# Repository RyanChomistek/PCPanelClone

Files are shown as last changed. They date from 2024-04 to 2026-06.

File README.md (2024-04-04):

To install go to releases and download and run the installer

once installed it should automatically start. it will auto generate a file called MixerSettings.json in your documents folder
 - in the file there is an array of dials, the index in the array corresponds to the index of the dial
 - for each dial there are three properties, Color, Target, and Processes
   - Color: an array that has 3 ints representing the color of the dial led
   - Target what the dial does. currently there are three states
     - 0: target processes (there should be annother property named Processes on the object). This means that the mixer will set the volume of all of the listed processes
     - 1: Master, sets the master volume
     - 2: Device, sets the volume of a specific output device (not sure if this one works yet)
     - 3: focused, set the volume of the currently focused window
   - Processes: an array of process strings. if Target is set to 3, then it will use this list to find the processes it wants to change

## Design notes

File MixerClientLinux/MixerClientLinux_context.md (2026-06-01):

---
name: project-linux-port
description: "Linux port of Windows MixerClient HID driver into MixerClientLinux — API substitutions, architecture, and build deps"
metadata: 
  node_type: memory
  type: project
  originSessionId: 93b12617-98bc-4457-a38f-4e3386a606ed
---

# MixerClientLinux — Linux port of MixerClient

Created `PCPanelClone/MixerClientLinux/` as a Linux equivalent of `PCPanelClone/MixerClient/`.
Only `.h` and `.cpp` files were ported (`.sln`/`.vcxproj` replaced with `CMakeLists.txt`).

## Files

| File | Notes |
|---|---|
| `HidReader.h/.cpp` | Linux HID layer |
| `VolumeMixerController.h/.cpp` | PulseAudio audio control |
| `MixerClient.cpp` | Entry point |
| `Util.h` | Error macros (int-based, not HRESULT) |
| `Holder.h` | Copied verbatim (generic C++) |
| `scope_guard.h` | Copied verbatim (pure C++) |
| `CMakeLists.txt` | C++20, links hidapi-hidraw + libpulse + x11 + nlohmann_json |

## Key API substitutions

| Windows | Linux |
|---|---|
| `SetupDiGetClassDevs` / `SetupDiEnumDeviceInterfaces` | `hid_enumerate()` (libhidapi) |
| `CreateFile` + `ReadFile`/`WriteFile` with `OVERLAPPED` | `hid_open_path` + `hid_read_timeout` / `hid_write` |
| `HidP_GetValueCaps` / `HidP_GetButtonCaps` / `HidP_GetData` | Custom HID descriptor parser using `HIDIOCGRDESC` ioctl + bit extraction |
| WASAPI (`IMMDevice`, `IAudioSessionManager2`, `ISimpleAudioVolume`) | PulseAudio threaded mainloop (`pa_context_get_sink_input_info_list`, `pa_context_set_sink_input_volume`) |
| `IAudioEndpointVolume` | `pa_context_get/set_sink_volume_by_name` |
| `GetForegroundWindow` + `QueryFullProcessImageNameW` | X11 `XGetInputFocus` + `_NET_WM_PID` + `/proc/<pid>/comm` |
| `SHGetFolderPath(CSIDL_PERSONAL)` | `getenv("HOME")` |
| `std::wstring` process names | `std::string` (UTF-8) |
| `Sleep(1000)` | `sleep(1)` |

## HID device target

Device filter: `usagePage == 0x01` (Generic Desktop), `usage == 0x37` (Dial).
The HID descriptor parser reads via `HIDIOCGRDESC` ioctl on the `/dev/hidraw*` node,
then parses Variable/Array input items, building `hidValues` (dials) and `hidButtons` maps
keyed by sequential DataIndex — matching Windows `HidP_GetData` semantics.

## Audio notes

- PulseAudio wrapper (`PulseSession` class) uses threaded mainloop with lock/wait/signal pattern.
- Per-app volume matches by substring of `PA_PROP_APPLICATION_PROCESS_BINARY`.
- Process names in `MixerSettings.json` need updating from `"firefox.exe"` → `"firefox"` etc.
- Settings file written to `$HOME/MixerSettings.json`.

## Build

```bash
cmake -B build -DCMAKE_BUILD_TYPE=Release
cmake --build build
```

Dependencies: `hidapi-hidraw`, `libpulse`, `x11`, `nlohmann_json`

udev rule needed to access `/dev/hidraw*` without root (Arduino Micro VID/PID, group `users` since `plugdev` doesn't exist on Arch):
```
SUBSYSTEM=="hidraw", ATTRS{idVendor}=="2341", ATTRS{idProduct}=="8037", MODE="0660", GROUP="users"
```
Install: `sudo tee /etc/udev/rules.d/99-arduino-micro.rules`, then `sudo udevadm control --reload && sudo udevadm trigger`

## Running as a background service

Systemd user service at `~/.config/systemd/user/mixer-client.service`:
```ini
[Unit]
Description=PCPanel Mixer Client
After=graphical-session.target pulseaudio.service

[Service]
ExecStart=/home/ryanc/github/PCPanelClone/MixerClientLinux/MixerClientLinux
Restart=on-failure
RestartSec=3

[Install]
WantedBy=default.target
```

```bash
systemctl --user daemon-reload
systemctl --user enable --now mixer-client.service
journalctl --user -u mixer-client.service -f   # view logs
```

## IDE diagnostics note

`std::ranges::sort` on lines 261–262 of `HidReader.cpp` shows a false-positive error in the IDE
because the parser doesn't see C++20 from CMake. Compiles correctly with `-std=c++20`.

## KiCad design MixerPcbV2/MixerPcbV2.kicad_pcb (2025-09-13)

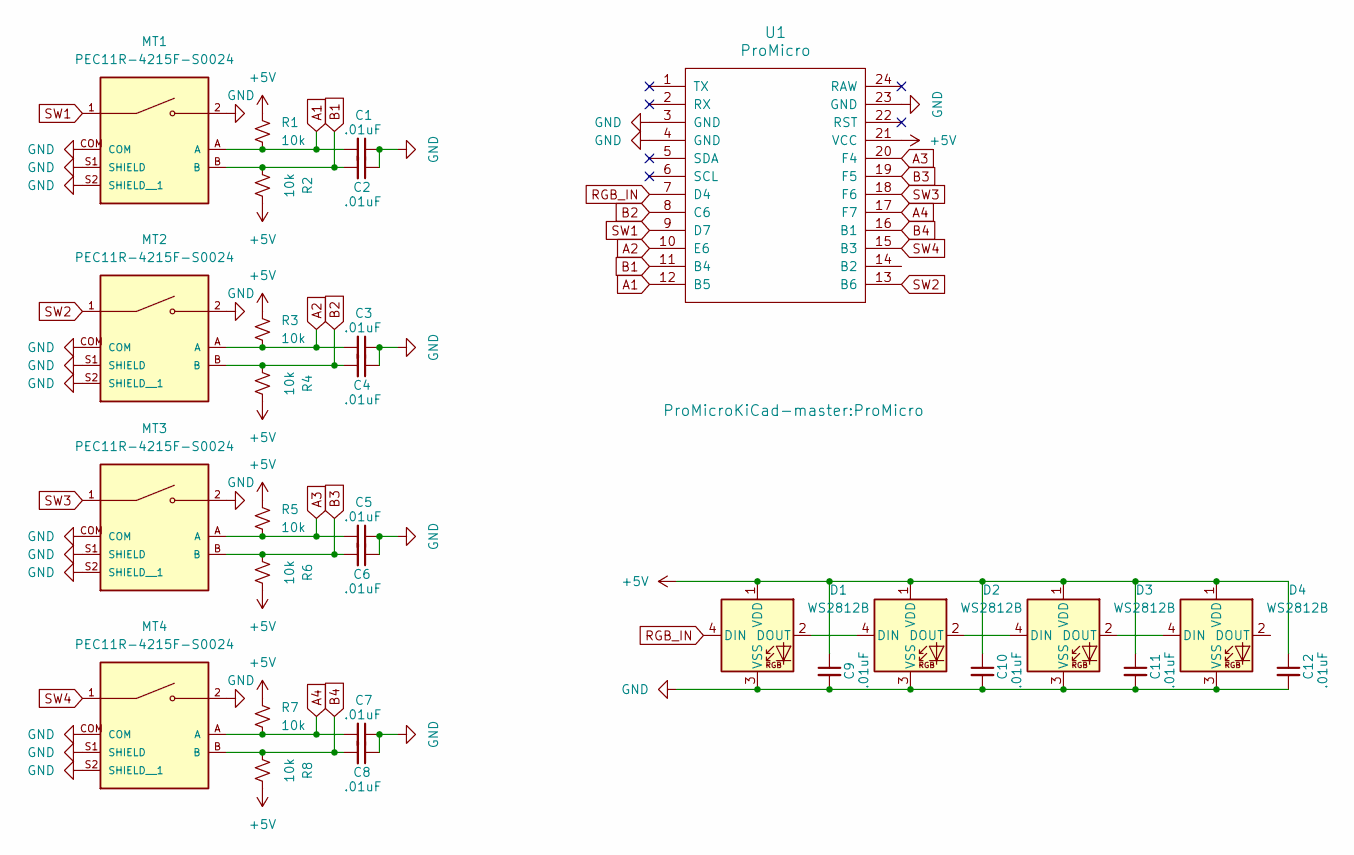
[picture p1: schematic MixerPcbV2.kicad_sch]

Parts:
C1, C2, C3, C4, C5, C6, C7, C8, C9, C10, C11, C12: .01uF; C_0805_2012Metric
D1, D2, D3, D4: WS2812B; LED_WS2812B_PLCC4_5.0x5.0mm_P3.2mm
MT1, MT2, MT3, MT4: PEC11R-4215F-S0024; XDCR_PEC11R-4215F-S0024; PARTREV Rev. 09/19
R1, R2, R3, R4, R5, R6, R7, R8: 10k; R_0805_2012Metric
U1: ProMicro

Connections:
+5V: C9.1, C10.1, C11.1, C12.1, D1.1 (VDD), D2.1 (VDD), D3.1 (VDD), D4.1 (VDD), R1.2, R2.1, R3.2, R4.1, R5.2, R6.1, R7.2, R8.1, U1.21 (VCC)
A1: C1.2, MT1.A, R1.1, U1.12 (B5)
A2: C3.2, MT2.A, R3.1, U1.10 (E6)
A3: C5.2, MT3.A, R5.1, U1.20 (F4)
A4: C7.2, MT4.A, R7.1, U1.17 (F7)
B1: C2.2, MT1.B, R2.2, U1.11 (B4)
B2: C4.2, MT2.B, R4.2, U1.8 (C6)
B3: C6.2, MT3.B, R6.2, U1.19 (F5)
B4: C8.2, MT4.B, R8.2, U1.16 (B1)
GND: C1.1, C2.1, C3.1, C4.1, C5.1, C6.1, C7.1, C8.1, C9.2, C10.2, C11.2, C12.2, D1.3 (VSS), D2.3 (VSS), D3.3 (VSS), D4.3 (VSS), MT1.2, MT1.COM, MT1.S1 (SHIELD), MT1.S2 (SHIELD__1), MT2.2, MT2.COM, MT2.S1 (SHIELD), MT2.S2 (SHIELD__1), MT3.2, MT3.COM, MT3.S1 (SHIELD), MT3.S2 (SHIELD__1), MT4.2, MT4.COM, MT4.S1 (SHIELD), MT4.S2 (SHIELD__1), U1.3 (GND), U1.4 (GND), U1.23 (GND)
unnamed: D1.2 (DOUT), D2.4 (DIN)
unnamed: D2.2 (DOUT), D3.4 (DIN)
unnamed: D3.2 (DOUT), D4.4 (DIN)
RGB_IN: D1.4 (DIN), U1.7 (D4)
SW1: MT1.1, U1.9 (D7)
SW2: MT2.1, U1.13 (B6)
SW3: MT3.1, U1.18 (F6)
SW4: MT4.1, U1.15 (B3)

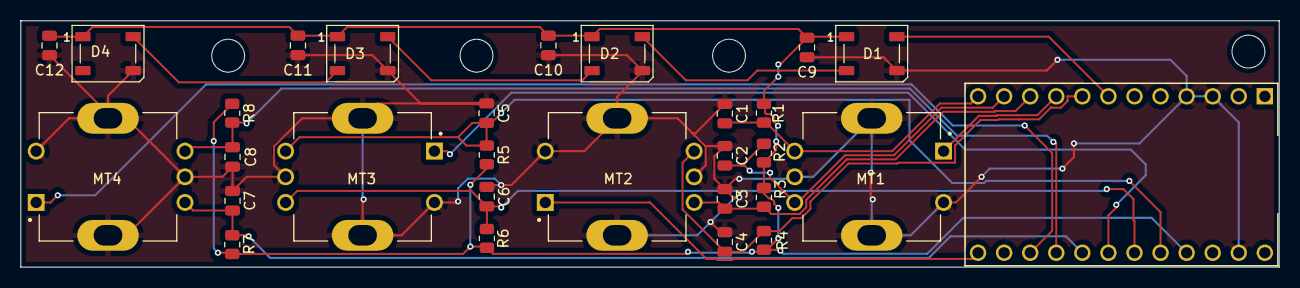
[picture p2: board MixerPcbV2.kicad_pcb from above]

Board: 2 copper layers, 122.6 x 24.0 mm, 29 parts (0 on the bottom side), 18 nets.

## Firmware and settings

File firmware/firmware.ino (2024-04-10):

#include "EncoderManager.h"
#include "LedManager.h"
#include "Serialization.h"

EncoderManager s_encoderManager;
LedManager s_ledManager;
unsigned long timeLastHeartBeatSent = 0;
unsigned long timeLastInputRecieved = 0;

void setup(){
  Serial.begin(115200);
  s_encoderManager.setup();
  s_ledManager.Setup(9);

  Serial.print(static_cast<long int>(OutputEventType::StartUp));
  Serial.print("\n");
  Serial.flush();

  timeLastHeartBeatSent = millis();
  timeLastInputRecieved = millis();
}

int msHeartBeatCycleTime = 1000;

void loop() {
  s_encoderManager.loop();

  if(!s_encoderManager.fAnyEncoderChanged && millis() - timeLastHeartBeatSent > msHeartBeatCycleTime)
  {
    timeLastHeartBeatSent = millis();

    char serialBuffer[255];
    sprintf(serialBuffer, "%ld\n", OutputEventType::HeartBeat);
    Serial.write(serialBuffer);
  }

  if(millis() - timeLastInputRecieved > 60000)
  {
    s_ledManager.TemporaryClearLEDs();
    timeLastInputRecieved = millis();

    char serialBuffer[255];
    sprintf(serialBuffer, "clearing LEDs|");
    Serial.write(serialBuffer);
  }

  // handle serial input
  while (Serial.available() > 0) 
  {
    // subtract by '0' to convert ascii char to int
    char next = Serial.read();

    if(next == ' ' || next == '\n')
    {
      // deliniation chars just skip
      continue;
    }

    // all of the inputs start with a number so if its not that its probably a bug
    if(next < '0' || next > '9')
    {
      char serialBuffer[255];
      sprintf(serialBuffer, "ERROR: BAD CHAR %c|", next);
      Serial.write(serialBuffer);
      continue;
    }

    InputEventType inputEvent = (InputEventType) next - '0';

    // char serialBuffer[255];
    // sprintf(serialBuffer, "in: %d %u|", inputEvent, millis() - timeLastInputRecieved);
    // Serial.write(serialBuffer);

    switch(inputEvent)
    {
      case InputEventType::color:
      {
        s_ledManager.UpdateLEDFromSerial();
        break;
      }
      case InputEventType::brightness:
      {
        s_ledManager.UpdateBrightnessFromSerial();
        break;
      }
      case InputEventType::HeartBeat:
      {
        break;
      }
    }

    timeLastInputRecieved = millis();
  }
}

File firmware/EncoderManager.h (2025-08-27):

#pragma once
#include <Arduino.h>
#include <Wire.h>
#include "Adafruit_MCP23017.h"
#include "Rotary.h"
#include "RotaryEncOverMCP.h"
#include "Serialization.h"

#if defined(ESP32) || defined(ESP8266)
#define INTERRUPT_FUNC_ATTRIB IRAM_ATTR
#else
#define INTERRUPT_FUNC_ATTRIB  
#endif

/* variable to indicate that an interrupt has occured */
volatile boolean awakenByInterrupt = false;

class EncoderManager
{
public:
static void RotaryEncoderChanged(Direction direction, int id, int count) {
    char serialBuffer[255];
    sprintf(serialBuffer, "%ld %d %d %d\n", OutputEventType::Dial, id, direction, count);
    Serial.write(serialBuffer);
}

static void RotaryEncoderSwitchPressed(int id)
{
  // char serialBuffer[255];
  // sprintf(serialBuffer, "%ld %d\n", OutputEventType::Button, id);
  // Serial.write(serialBuffer);
}

void setup()
{
  pinMode(arduinoIntPin,INPUT);

  mcp.begin();      // use default address 0
  mcp.readINTCAPAB(); //read this so that the interrupt is cleared

  //initialize all rotary encoders

  //Setup interrupts, OR INTA, INTB together on both ports.
  //thus we will receive an interrupt if something happened on
  //port A or B with only a single INT connection.
  mcp.setupInterrupts(true,false,LOW);

  //Initialize input encoders (pin mode, interrupt)
  for(int i=0; i < numEncoders; i++) {
      rotaryEncoders[i].init();
  }

  attachInterrupt(digitalPinToInterrupt(arduinoIntPin), intCallBack, FALLING);
}

// The int handler will just signal that the int has happened
// we will do the work from the main loop.
static void INTERRUPT_FUNC_ATTRIB intCallBack() {
    awakenByInterrupt=true;
}

void checkInterrupt() {
    if(awakenByInterrupt) {
      // disable interrupts while handling them.
      detachInterrupt(digitalPinToInterrupt(arduinoIntPin));
      handleInterrupt();
      attachInterrupt(digitalPinToInterrupt(arduinoIntPin),intCallBack,FALLING);
    }
}

void handleInterrupt(){
  fAnyEncoderChanged = true;

  //An interrupt occurred on some MCP object.
  //since all of them are ORed together, we don't
  //know exactly which one has fired.
  //just read all of them, pre-emptively.

  for(int j = 0; j < numMCPs; j++) {
    uint16_t gpioAB = allMCPs[j]->readINTCAPAB();
    // we need to read GPIOAB to clear the interrupt actually.
    volatile uint16_t dummy = allMCPs[j]->readGPIOAB();
    for (int i=0; i < numEncoders; i++) {
      //only feed this in the encoder if this
      //is coming from the correct MCP
      if(rotaryEncoders[i].getMCP() == allMCPs[j])
      {
        rotaryEncoders[i].feedInput(gpioAB);
      }
            
    }
  }

  cleanInterrupts();
}

// handy for interrupts triggered by buttons
// normally signal a few due to bouncing issues
void cleanInterrupts(){
#ifdef __AVR__
    EIFR=0x01;
#endif
    awakenByInterrupt=false;
}

void loop() {
  fAnyEncoderChanged = false;

  //Check if an interrupt has occurred and act on it
  checkInterrupt();
}

 bool fAnyEncoderChanged = false;

private:
  /* Our I2C MCP23017 GPIO expanders */
  Adafruit_MCP23017 mcp;

  //Array of pointers of all MCPs if there is more than one
  Adafruit_MCP23017* allMCPs[1] = { &mcp };
  const int numMCPs = (int)(sizeof(allMCPs) / sizeof(*allMCPs));

  /* the INT pin of the MCP can only be connected to
  * an interrupt capable pin on the Arduino, either
  * D3 or D2.
  * */
  byte arduinoIntPin = 3;

  /* Array of all rotary encoders and their pins */
  RotaryEncOverMCP rotaryEncoders[4] = {
      RotaryEncOverMCP(&mcp, 12 /*pinDT*/, 13 /*pinCLK*/, 11 /*pinSW*/, &RotaryEncoderChanged, &RotaryEncoderSwitchPressed, 0),
      RotaryEncOverMCP(&mcp, 9 /*pinDT*/, 10 /*pinCLK*/, 8 /*pinSW*/, &RotaryEncoderChanged, &RotaryEncoderSwitchPressed, 1),
      RotaryEncOverMCP(&mcp, 6 /*pinDT*/, 5 /*pinCLK*/, 7 /*pinSW*/, &RotaryEncoderChanged, &RotaryEncoderSwitchPressed, 2),
      RotaryEncOverMCP(&mcp, 3 /*pinDT*/, 2 /*pinCLK*/, 4 /*pinSW*/, &RotaryEncoderChanged, &RotaryEncoderSwitchPressed, 3),
  };
  const int numEncoders = (int)(sizeof(rotaryEncoders) / sizeof(*rotaryEncoders));
};

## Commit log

2023-10-21 fixing new mixer device to work with client
    [EncoderManager.h, RotaryEncOverMCP.h, VolumeMixerController.cpp]
2023-10-22 making new device code work with led signals
2024-03-17 fixing issues with printf and long int
2024-03-18 fixing issue with reading next command blocking
    [EncoderManager.h, LedManager.h, VolumeMixerController.cpp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]
2024-03-18 adding led flash for current dial
2024-03-18 changing default led settings
2024-04-04 disabling logging via bool and fixing leaks
    [LedManager.h, VolumeMixerController.cpp, VolumeMixerController.h]
2024-04-06 adding mute buttons
2024-04-07 adding debounce to switch
2024-04-07 resetting everything back to a good build state
    [VolumeMixerController.cpp]
2024-04-07 fixing a couple issues with fetching process string
    [VolumeMixerController.cpp]
2024-04-08 fixing issues with the nSize carrying over from the last string query
    [VolumeMixerController.cpp]
2024-04-09 making mute now toggle LED
2024-04-10 adding mute state query on heatbeat to check all mute states
2025-08-27 starting switchover to HID
2025-08-30 updating to work with out reports
    [MixerPcbV2.kicad_pcb, MixerPcbV2.kicad_sch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]
2025-09-13 updating to more hid stuff
    [MixerPcbV2.kicad_pcb]
